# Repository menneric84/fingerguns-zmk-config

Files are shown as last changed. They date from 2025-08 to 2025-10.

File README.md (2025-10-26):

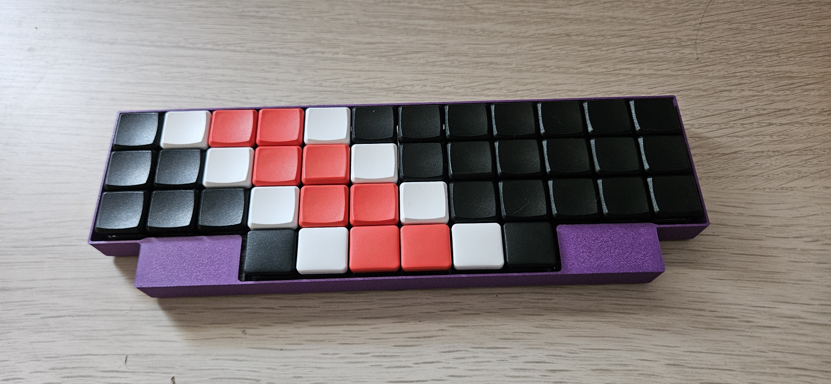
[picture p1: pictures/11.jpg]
12col variant of rick-plank

# v1.1
v1.1 includes support for one ALPS EC12 rotary encoder that can be placed in either the right or the left corner.  Both sockets are wired to the same pins (gpio 0 and gpio 1), so only one can be used at a time.

Pinout is identical, but the ZMK repo is not currently configured for rotary encoders.  I will dive into rotary encoders in ZMK when I have time.

Other changes: moved MCU closer to the edge, rotated hotswaps on col10 (the 11th column) to make design of the 10col case easier.

# ZMK
YOU MUST CHECK rick-plank.overlay TO ENSURE THE PROPER PHYSICAL LAYOUT IS CHOSEN

Please see the comments on line 4 of rick-plank.overlay.  In the 'chosen' node, you will need to adjust zmk,physical-layout depending on if you are using the 12 column variant or the 10 column variant of the Rick Plank PCB.

The 12 column is represented by &layout_12col
The 10 column is represented by &layout_10col

YOU MUST SELECT OR CREATE AN APPROPRIATE KEYMAP

In the ergomech community a keymap is an intensely personal thing.  That being said, I've included my own 12 column and 10 column keymaps in case you need somewhere to start.  Please note that rick-plank.keymap is intended for the 10 column variant.  A 12 column keymap is also included under the name rick-plank.keymap.12col.  If you wish to use 12 columns, simply append '.10col' to the default keymap and delete '.12col' from the other one.

# QMK?
I haven't tried it, but there's no reason it wouldn't work fine.  You'll find the pinout in the kicad schematic.  Please reach out and let me know how it goes!  If you get it up and running I'd be happy to add a QMK option to the repo.

# BOM
36-42 choc switches & keycaps  
36-42 choc hotswaps  
36-42 smd diodes  
6 M2 heat set inserts  
6 M2 x 6mm screws  
6 rubber bumpons (recommended)  
1 MSK12C02 switch  
1 Panasonic EVQPUJ_EVQPUA button  
1 pro micro form factor MCU  
1 301230 110mAh battery (optional)  

If you are confused about switches, all parts except the inserts and screws can be sourced from typeractive.xyz.

# BUILDING
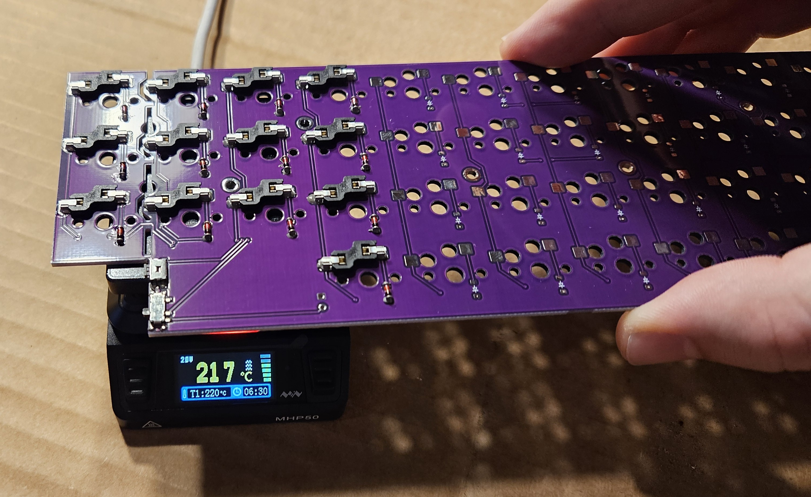
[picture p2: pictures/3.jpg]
rick-plank on the hotplate

If planning to use the case, the MCU should be soldered with the included headers, NOT sockets.  The sockets add too much height to fit in the case.  A hot plate is recommended for assembly, as it makes the whole process very quick and easy.  Assembly is possible by hand with a soldering iron, though it can be delicate and frustrating.  For the diodes and switches, I recommend tinning one pad first, then placing the component with tweezers before soldering the other side.  Some of the photos show a battery pigtail, but ultimately I decided to solder the battery wires directly to the board and stick the battery down with a command strip.

# CASES
12col rick-plank 3d printed case
Files are included to 3d print a case for the 12col variant, designed by my brother.  PCB is secured with 6 M2 heat set inserts. The 10col case is still in development, but will be added to the repo when it's done.  I've also included a .step file of the PCB under /gerbers_and_kicad if you'd like to design your own.

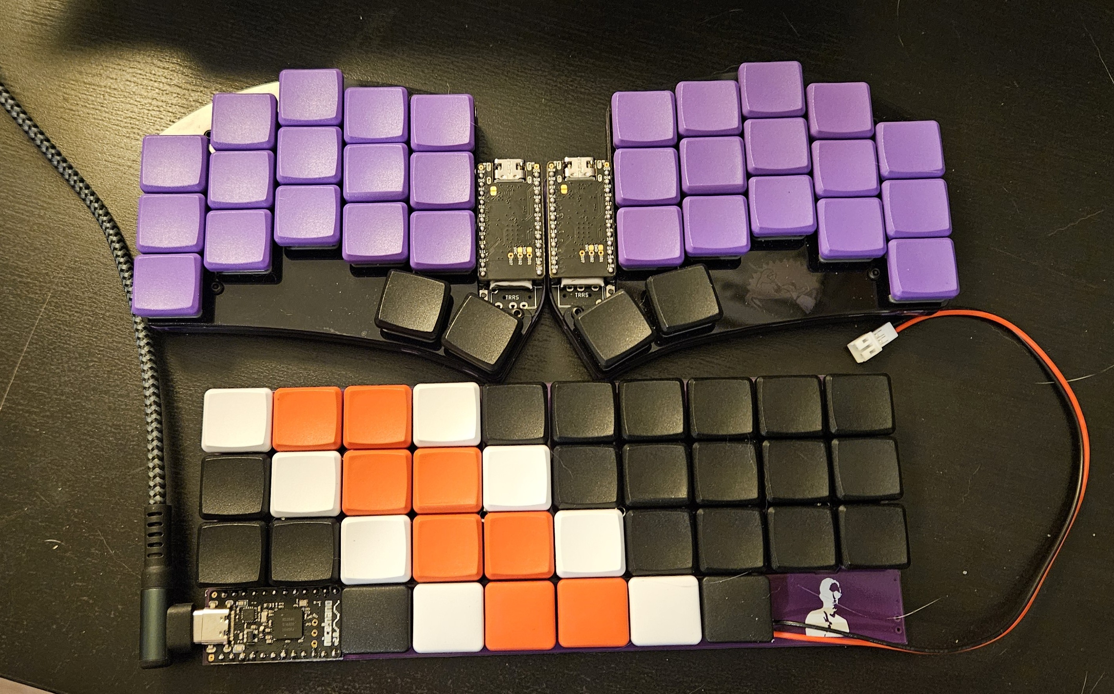
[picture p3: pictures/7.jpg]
Caseless 10col

Rick Plank is also perfectly useable without a case if you stick a few bumpons on the hotswaps.  I placed a total of six, at the four corners and at the corners of the bottom row.

# LICENSING
All hardware in this repo is licensed under CERN-OHL-S-2.0, available at https://gitlab.com/ohwr/project/cernohl/-/wikis/uploads/819d71bea3458f71fba6cf4fb0f2de6b/cern_ohl_s_v2.txt

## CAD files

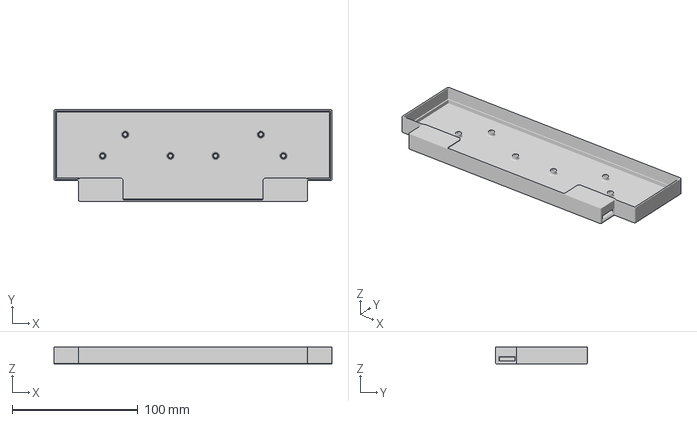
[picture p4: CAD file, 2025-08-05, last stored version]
case/12col_case.3mf
221.5 x 73.0 x 13.2 mm

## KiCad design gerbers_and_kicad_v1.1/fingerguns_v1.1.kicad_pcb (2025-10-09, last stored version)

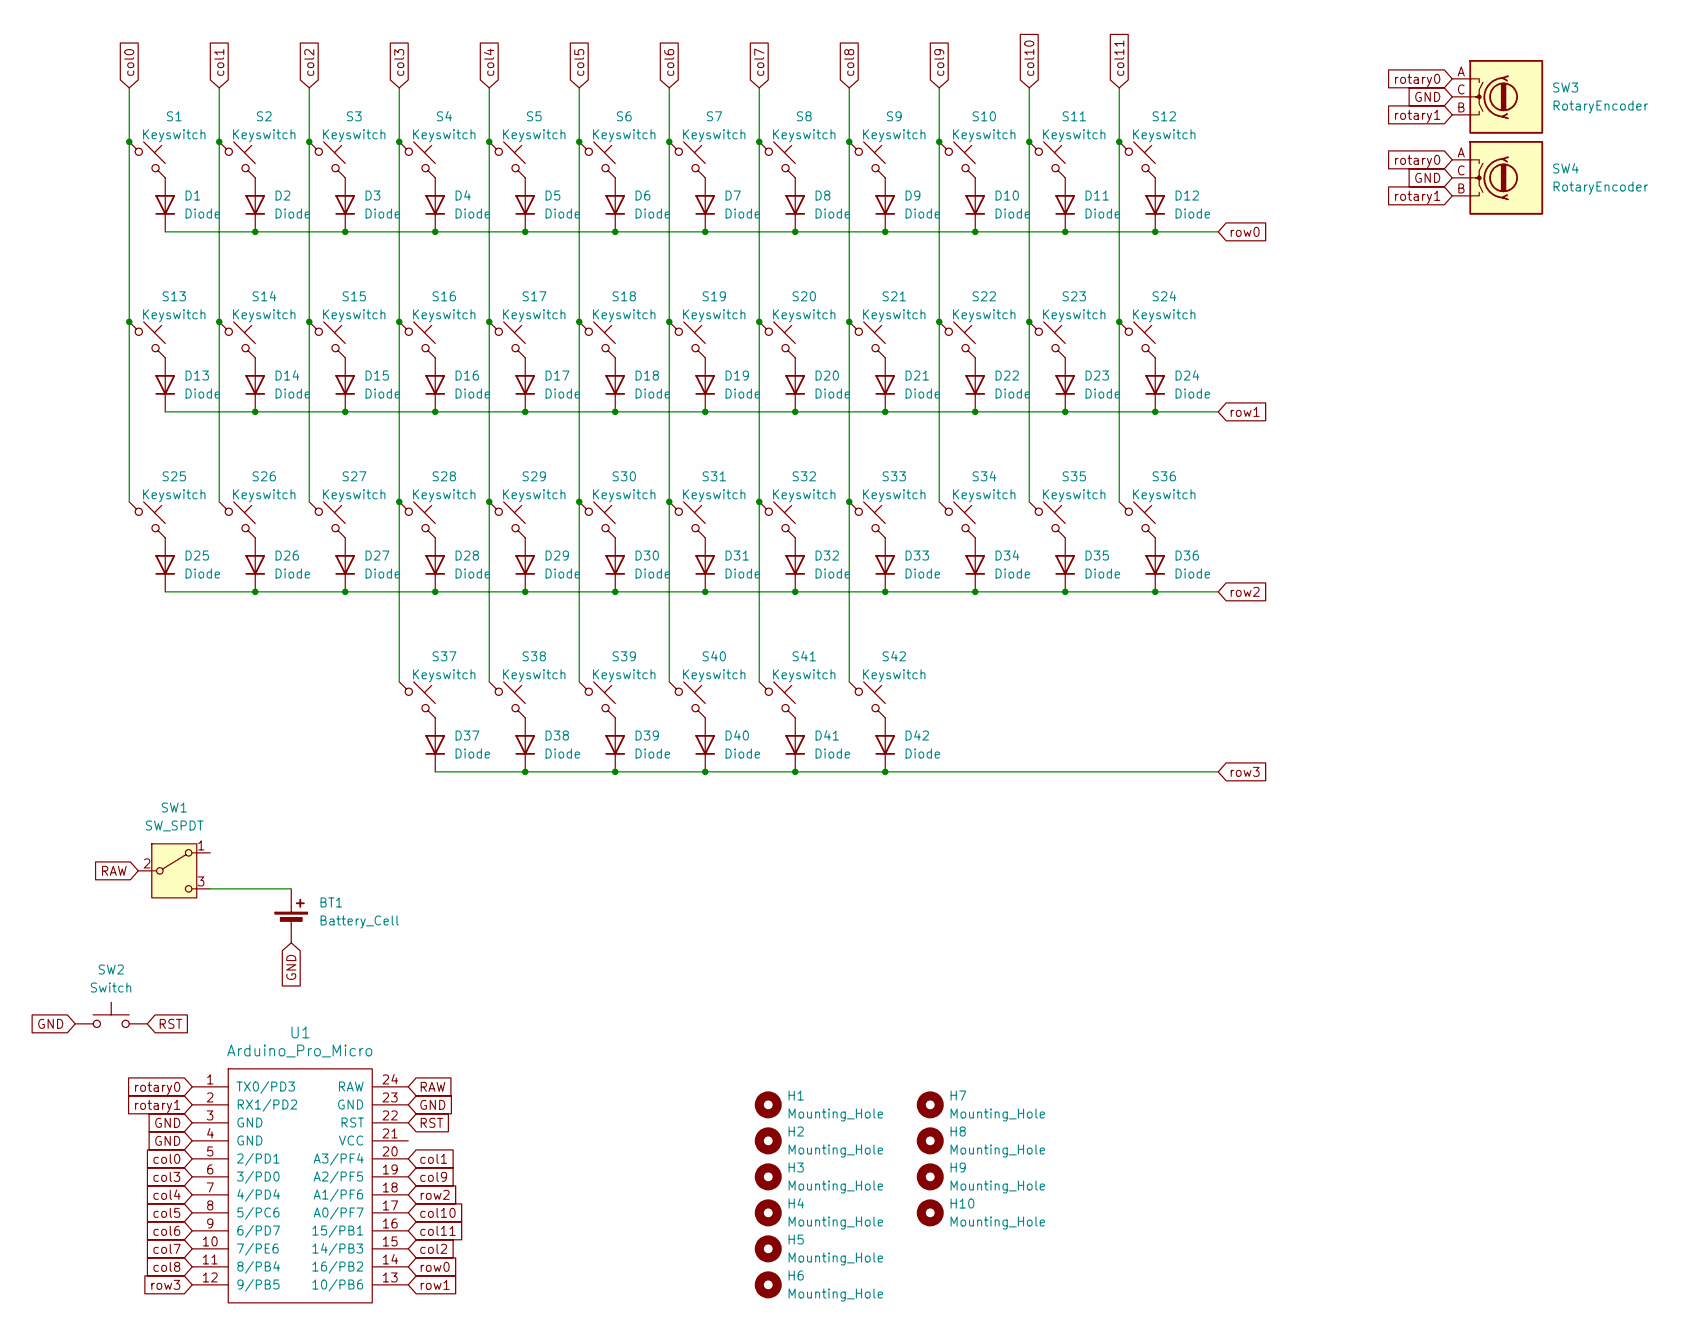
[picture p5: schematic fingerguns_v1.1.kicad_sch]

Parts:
BT1: Battery_Cell; Battery
D1, D2, D3, D4, D5, D6, D7, D8, D9, D10, D11, D12, D13, D14, D15, D16, D17, D18, D19, D20, D21, D22, D23, D24, D25, D26, D27, D28, D29, D30, D31, D32, D33, D34, D35, D36, D37, D38, D39, D40, D41, D42: Diode; Diode_SOD-123
H1, H2, H3, H4, H5, H6: Mounting_Hole; MountingHole_2.2mm_M2_DIN965_Pad_TopBottom
H7, H8, H9, H10: Mounting_Hole; MountingHole_3.2mm_M3
S1, S2, S3, S4, S5, S6, S7, S8, S9, S10, S11, S12, S13, S14, S15, S16, S17, S18, S19, S20, S21, S22, S23, S24, S25, S26, S27, S28, S29, S30, S31, S32, S33, S34, S35, S36, S37, S38, S39, S40, S41, S42: Keyswitch; Hotswap_Choc_V1_1.00u no silkscreen
SW1: SW_SPDT; Switch_MSK12C02
SW2: Switch; Panasonic_EVQPUJ_EVQPUA
SW3, SW4: RotaryEncoder; RotaryEncoder_Alps_EC12E_Vertical_H20mm
U1: Arduino_Pro_Micro

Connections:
GND: BT1.2 (-), SW2.1, SW3.C, SW4.C, U1.3 (GND), U1.4 (GND), U1.23 (GND)
unnamed: BT1.1 (+), SW1.3 (C)
unnamed: D1.2 (A), S1.1
unnamed: D2.2 (A), S2.1
unnamed: D3.2 (A), S3.1
unnamed: D4.2 (A), S4.1
unnamed: D5.2 (A), S5.1
unnamed: D6.2 (A), S6.1
unnamed: D7.2 (A), S7.1
unnamed: D8.2 (A), S8.1
unnamed: D9.2 (A), S9.1
unnamed: D10.2 (A), S10.1
unnamed: D11.2 (A), S11.1
unnamed: D12.2 (A), S12.1
unnamed: D13.2 (A), S13.1
unnamed: D14.2 (A), S14.1
unnamed: D15.2 (A), S15.1
unnamed: D16.2 (A), S16.1
unnamed: D17.2 (A), S17.1
unnamed: D18.2 (A), S18.1
unnamed: D19.2 (A), S19.1
unnamed: D20.2 (A), S20.1
unnamed: D21.2 (A), S21.1
unnamed: D22.2 (A), S22.1
unnamed: D23.2 (A), S23.1
unnamed: D24.2 (A), S24.1
unnamed: D25.2 (A), S25.1
unnamed: D26.2 (A), S26.1
unnamed: D27.2 (A), S27.1
unnamed: D28.2 (A), S28.1
unnamed: D29.2 (A), S29.1
unnamed: D30.2 (A), S30.1
unnamed: D31.2 (A), S31.1
unnamed: D32.2 (A), S32.1
unnamed: D33.2 (A), S33.1
unnamed: D34.2 (A), S34.1
unnamed: D35.2 (A), S35.1
unnamed: D36.2 (A), S36.1
unnamed: D37.2 (A), S37.1
unnamed: D38.2 (A), S38.1
unnamed: D39.2 (A), S39.1
unnamed: D40.2 (A), S40.1
unnamed: D41.2 (A), S41.1
unnamed: D42.2 (A), S42.1
RAW: SW1.2 (B), U1.24 (RAW)
RST: SW2.2, U1.22 (RST)
col0: S1.2, S13.2, S25.2, U1.5 (2/PD1)
col1: S2.2, S14.2, S26.2, U1.20 (A3/PF4)
col2: S3.2, S15.2, S27.2, U1.15 (14/PB3)
col3: S4.2, S16.2, S28.2, S37.2, U1.6 (3/PD0)
col4: S5.2, S17.2, S29.2, S38.2, U1.7 (4/PD4)
col5: S6.2, S18.2, S30.2, S39.2, U1.8 (5/PC6)
col6: S7.2, S19.2, S31.2, S40.2, U1.9 (6/PD7)
col7: S8.2, S20.2, S32.2, S41.2, U1.10 (7/PE6)
col8: S9.2, S21.2, S33.2, S42.2, U1.11 (8/PB4)
col9: S10.2, S22.2, S34.2, U1.19 (A2/PF5)
col10: S11.2, S23.2, S35.2, U1.17 (A0/PF7)
col11: S12.2, S24.2, S36.2, U1.16 (15/PB1)
rotary0: SW3.A, SW4.A, U1.1 (TX0/PD3)
rotary1: SW3.B, SW4.B, U1.2 (RX1/PD2)
row0: D1.1 (K), D2.1 (K), D3.1 (K), D4.1 (K), D5.1 (K), D6.1 (K), D7.1 (K), D8.1 (K), D9.1 (K), D10.1 (K), D11.1 (K), D12.1 (K), U1.14 (16/PB2)
row1: D13.1 (K), D14.1 (K), D15.1 (K), D16.1 (K), D17.1 (K), D18.1 (K), D19.1 (K), D20.1 (K), D21.1 (K), D22.1 (K), D23.1 (K), D24.1 (K), U1.13 (10/PB6)
row2: D25.1 (K), D26.1 (K), D27.1 (K), D28.1 (K), D29.1 (K), D30.1 (K), D31.1 (K), D32.1 (K), D33.1 (K), D34.1 (K), D35.1 (K), D36.1 (K), U1.18 (A1/PF6)
row3: D37.1 (K), D38.1 (K), D39.1 (K), D40.1 (K), D41.1 (K), D42.1 (K), U1.12 (9/PB5)

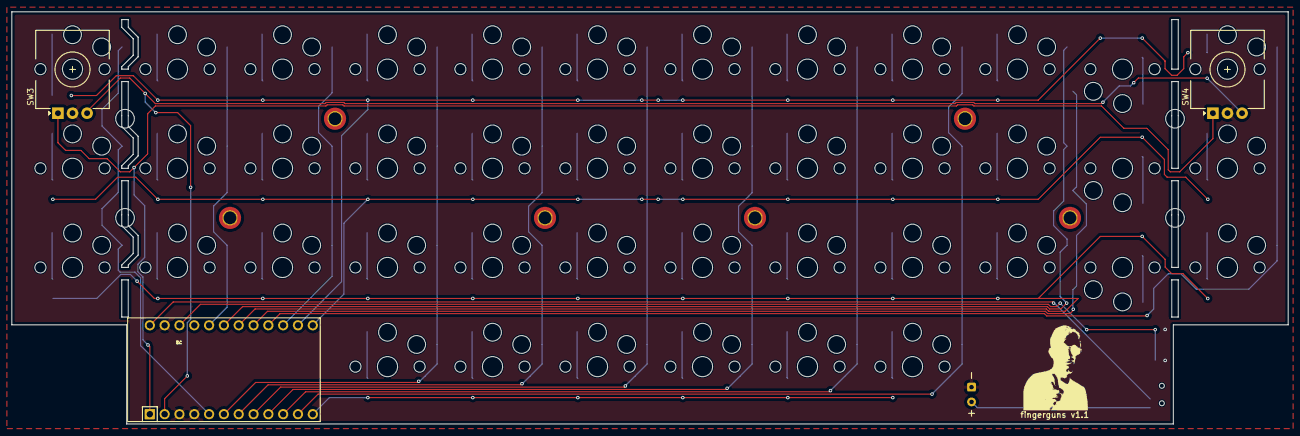
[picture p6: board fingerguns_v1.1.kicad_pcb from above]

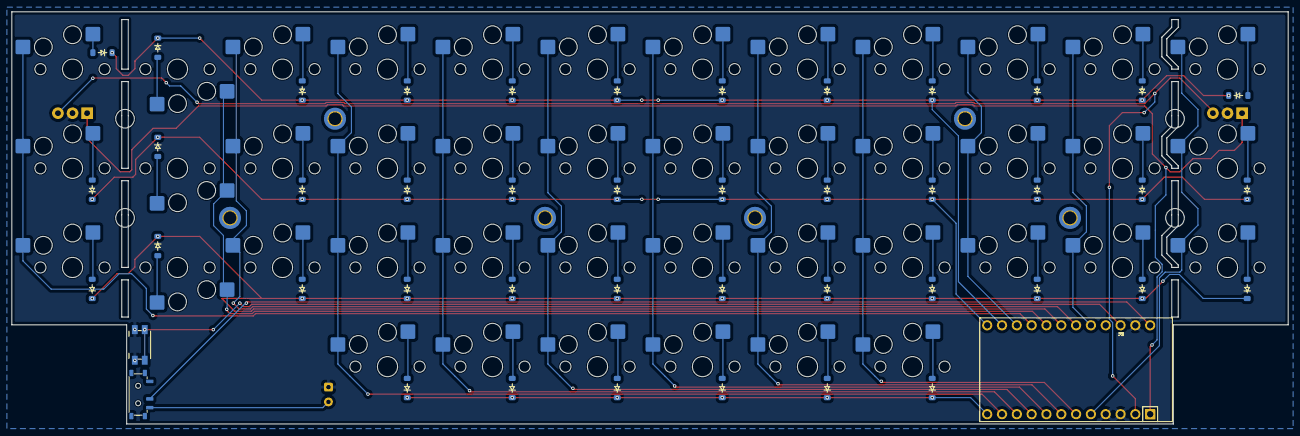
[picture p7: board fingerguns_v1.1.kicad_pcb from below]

Board: 2 copper layers, 218.8 x 70.7 mm, 100 parts (44 on the bottom side), 64 nets.

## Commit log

2024-12-12 added Kconfig.shield, Kconfig.defconfig, fingerguns.conf
2024-12-12 Added fingerguns.overlay and README.md. NOTE: correct transform must be chosen in fingerguns.overlay
2024-12-12 added fingerguns.zmk.yml
2024-12-12 Added physical layout in fingerguns.overlay, adjusted README.md
2024-12-13 Changed fingerguns.overlay line 63 columns to 12
2024-12-13 added to fingerguns.overlan kscan1
2024-12-13 Separated layouts to fingerguns-layouts.dtsi, fixed col-gpio in kscan0 and kscan1
2025-08-05 added 12col_case.3mf
    [12col_case.3mf]
2025-08-05 added gerbers and kicad files
    [bom.csv, designators.csv, ortho_4x12_choc_unibody_breakaway.kicad_pcb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]
2025-10-09 uploaded v1.1 gerbers and kicad files
    [fingerguns_v1.1.kicad_pcb, fingerguns_v1.1.kicad_sch, fingerguns_v1.1_bom.csv]
2025-10-26 Clean up fingerguns.keymap by removing comments
    Removed extensive comments and configuration for home row mods and macros.
2025-10-26 Update GPIO assignments in fingerguns overlay
2025-10-26 Update GPIO pin assignments in fingerguns overlay
2025-10-26 Update GPIO configuration in fingerguns.overlay
